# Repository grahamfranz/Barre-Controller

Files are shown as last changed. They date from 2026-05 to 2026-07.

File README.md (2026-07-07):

# Barre Controller

A parametric Eurorack-style control interface with flexible barres and top-mounted 3.5 mm jacks.

## Overview

The Barre Controller features:
- **Leaf-spring flex barres**: Flexible middle sections with piezo sensors for dynamic control
- **3.5 mm jacks**: Top-mounted panel jacks with a ~6 mm threaded barrel — any standard 3.5 mm panel-mount jack works (e.g. PJ398SM / "Thonkiconn")
- **Modular array**: Configurable number of barres with adjustable pitch

## Design Details

### Barre Architecture
Each barre consists of three sections:
- **Near end block**: Houses the near mounting screw
- **Middle (flex section)**: Thin, flexible member that bows when pressed, with piezo contact on the underside
- **Far end block**: Houses the jack pocket and far screw, with wire routing to the piezo

### Assembly
- Barres mount onto a continuous rail on the base for lateral alignment
- Two screws per barre clamp it down to the base
- Near screw: through the near end block
- Far screw: through the far end block, in front of the jack pocket

#### Hardware (per barre: 2 screws)
- **Screws:** M3, inserted from the top; the head sits proud on the end blocks (clear of the flex pad). The clamp stack is 20 mm (14 mm barre + 6 mm base), so a standard **M3×20** seats flush — the tip lands right at the base underside with full nut engagement, no protrusion and **no filing or cutting needed**. (No top counterbore: at the far screw a recessed head would break through the thin jack shoulder into the jack pocket.)
- **Nuts:** M3 hex nuts drop into the recessed **hex nut traps** on the base underside — they seat flat-to-flat and won't spin, so you can tighten entirely from the top. Because the barres see repeated pressing (cyclic load), use **nyloc nuts or a dab of threadlocker** so they don't back off. A nyloc sits slightly proud of the base underside; the rubber feet noted below absorb that.

### Printing
- **Base**: Print flat on bed (rail ridge points up)
- **Barre**: Print upside down so cutouts open upward during printing
  - Piezo indent, wire channel, jack pocket, and notch all print cleanly
  - Small bridge under jack pocket is FDM-friendly

#### Plate size and per-part STLs

The `both` render lays the base and all four barres out side-by-side, which spans
~245 mm in X — wider than most build plates. For smaller plates, print the parts
separately using the per-part STLs in `Renders/`:

| File | Part | Footprint | Notes |
|---|---|---|---|
| `barre_controller_base.stl` | Base (1×) | 130 × 157 × 9 mm | Print flat, rail up |
| `barre_controller_barre.stl` | Barre (print `num_barres`×) | 110 × 28 × 14 mm | Already in print orientation; duplicate in your slicer |
| `barre_controller_both.stl` | Base + 4 barres together | 245 × 157 mm | Single-plate layout (large plates only) |
| `barre_controller_assembled.stl` | Assembled preview | — | Visualization only, not printable as one piece |

For the default 4-barre array, print `barre_controller_base.stl` once and
`barre_controller_barre.stl` four times (arrange ~31 mm apart in Y, matching the
`both` layout). To regenerate any STL: `openscad -o Renders/barre_controller_<part>.stl -D 'part="<part>"' barre_controller.scad`

## File Structure

- `barre_controller.scad` - Main parametric model

## Customization

Key parameters in `barre_controller.scad`:

| Parameter | Default | Purpose |
|---|---|---|
| `num_barres` | 4 | Number of barres in the array |
| `barre_pitch` | 37 mm | Center-to-center spacing between barres |
| `barre_length` | 110 mm | Total length of each barre |
| `middle_thickness` | 5 mm | Flex section thickness (smaller = more flex; stiffness ~ thickness³) |
| `jack_offset_from_end` | 14 mm | Distance from far end to jack pocket center |
| `include_feet` | false | Enable corner feet for base support (experimental) |
| `foot_d` | 14 mm | Diameter of corner feet (tunable when enabled) |

## Manufacturing Notes

- Material: PLA or similar suitable for FDM printing
- Print orientation: See "Printing" section above
- **Base deflection:** The base is 6 mm thick by default, which resists press deflection reasonably well (and sets the 20 mm clamp stack for a flush M3×20). The corner feet feature is disabled by default (`include_feet = false`) because small feet don't effectively prevent base flex. If you still see flex, increase `base_thickness` in 5 mm steps to keep a standard screw flush (6 mm → M3×20, 11 mm → M3×25, 16 mm → M3×30), add adhesive rubber pads (~12 mm diameter) to the underside corners, or experiment with feet at larger `foot_d` (e.g. 18–20 mm)
- Piezo sensors are glued to the bottom of each middle section
- Jack bodies mount from below through the pocket opening; the threaded barrel passes up through the top shoulder and is secured with the jack's own nut on top
- Wire routing connects jack terminals to piezo sensor

## License

Public domain / CC0

## Enclosure Mode (Optional)

The barre controller can optionally be printed as a two-part enclosure to house a circuit board (e.g., circuit-mesh prototyping board).

### Enabling Enclosure Mode

In the OpenSCAD Customizer:
1. Set `with_enclosure` to `true`
2. Choose a render option:
   - `enclosure_shell` - Just the upper housing
   - `enclosure_panel` - Just the lower circuit board mount
   - `enclosure_both` - Both parts side-by-side for printing
   - `enclosure_assembled` - View of assembled enclosure with barres

### Enclosure Parameters

| Parameter | Default | Purpose |
|---|---|---|
| `enclosure_height` | 15 mm | Height of upper shell walls |
| `board_standoff_height` | 3 mm | Height of circuit board above lower panel |
| `piezo_hole_d` | 3.5 mm | Diameter of piezo wire pass-through holes |
| `lid_thickness` | 3 mm | Thickness of lower panel |
| `board_fastener_type` | "hex_nut" | Fastening style: "hex_nut", "square_nut", "self_tap" |
| `nut_pocket_depth` | 2.4 mm | Depth of hex-nut recess (tune per nut size) |
| `screw_margin` | 13 mm | Distance from corner to standoff center |
| `include_edge_guides` | true | Add shallow edge guides for panel alignment |
| `include_switch` | true | Add M16x2 threaded barrel power switch pocket |
| `switch_d` | 14.5 mm | Hole diameter for M16x2 switch (slight clearance) |

### Assembly

1. Print both parts (upper shell and lower panel)
2. *(Hex/square nut modes only)* Insert M3 nuts into corner pockets on the lower panel's underside
3. Mount your circuit board (e.g., circuit-mesh) to the standoffs on the lower panel using M3 screws from underneath
4. Lower the upper shell onto the lower panel, aligning corner posts
5. Insert M3 machine screws from the top and tighten into the nut pockets
6. Route piezo wires from the barres through the floor holes to your circuit board
7. Solder or connect piezo leads to your circuit board

### Power Switch (Enclosure Mode)

If `include_switch = true`, the upper shell includes a power switch pocket on the front-left face at mid-height for ergonomic thumb access.

**Switch type:** M16x2 threaded barrel (same mounting style as the Thonkiconn jacks)
- Hole diameter: 14.5 mm (for M16x2 clearance)
- Thread the switch barrel through the hole from the front
- Secure with M16x2 hex nut on the inside
- Route the switch leads down to your circuit board (e.g., between power supply and main microcontroller rail)
- Recommended switches: Latching toggle, pushbutton, or rotary switches with M16x2 threads (widely available in Eurorack supply shops)

### Backward Compatibility

When `with_enclosure = false`, the original single-piece base is rendered (default behavior). All original parameters and render modes remain unchanged.

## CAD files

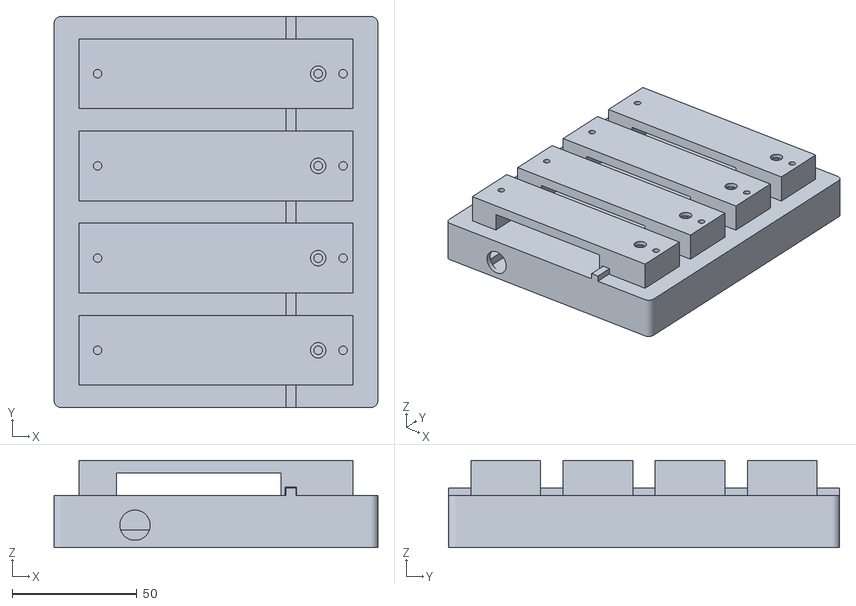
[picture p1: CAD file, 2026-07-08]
Renders/enclosure/enclosure_assembled.stl
130.0 x 157.0 x 35.0

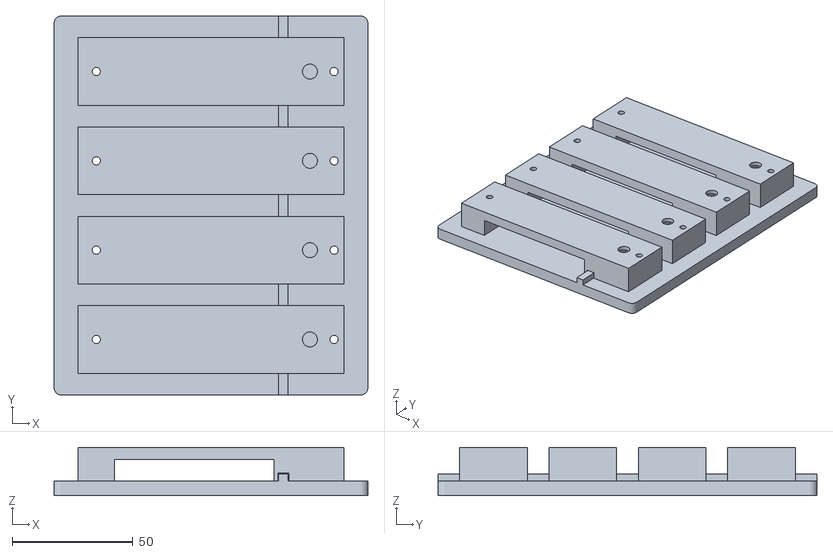
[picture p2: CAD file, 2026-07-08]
Renders/barre_controller_assembled.stl
130.0 x 157.0 x 20.0

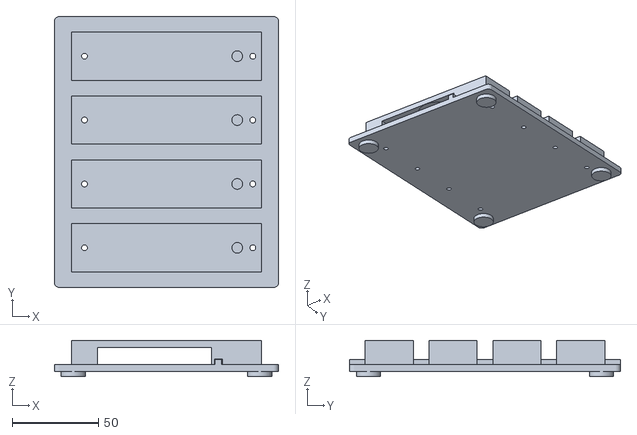
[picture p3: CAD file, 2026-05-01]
Renders/original_assembled.stl
130.0 x 157.0 x 21.0

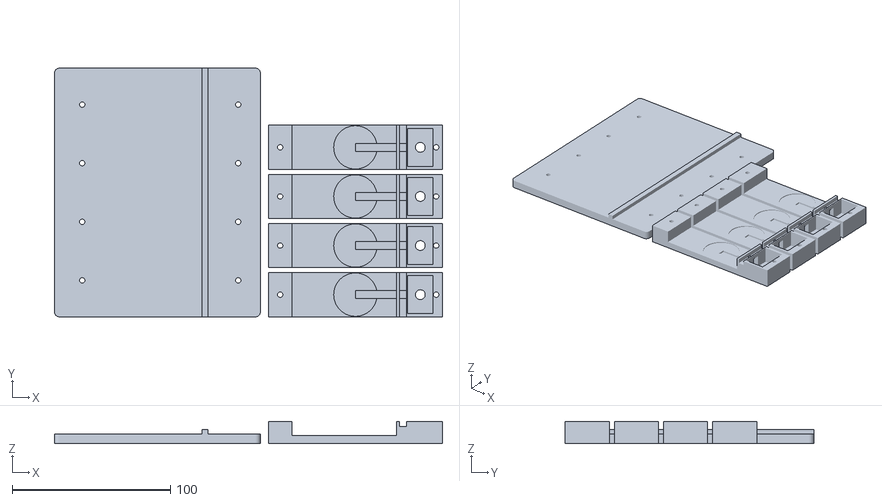
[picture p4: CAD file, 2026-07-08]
Renders/barre_controller_both.stl
245.0 x 157.0 x 14.0

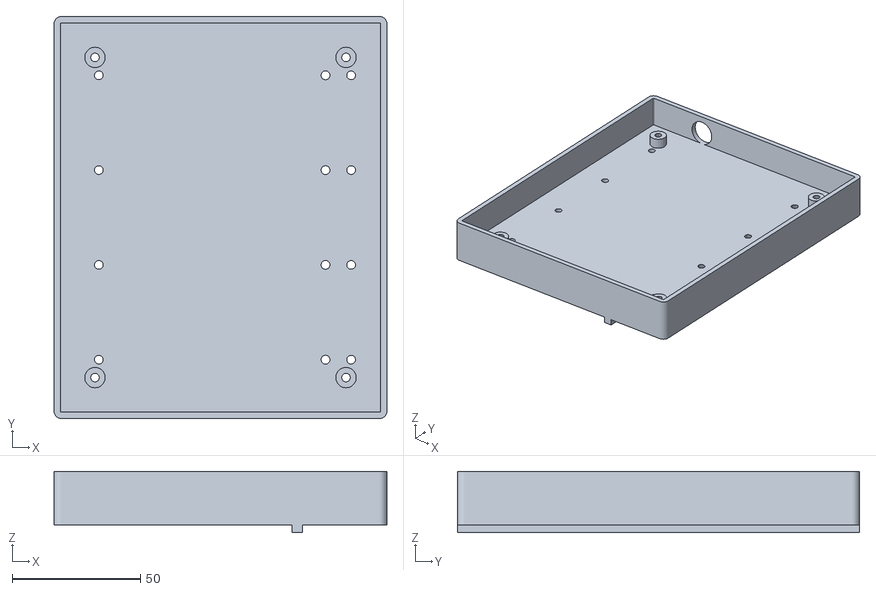
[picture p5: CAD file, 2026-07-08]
Renders/enclosure/enclosure_shell.stl
130.0 x 157.0 x 24.0

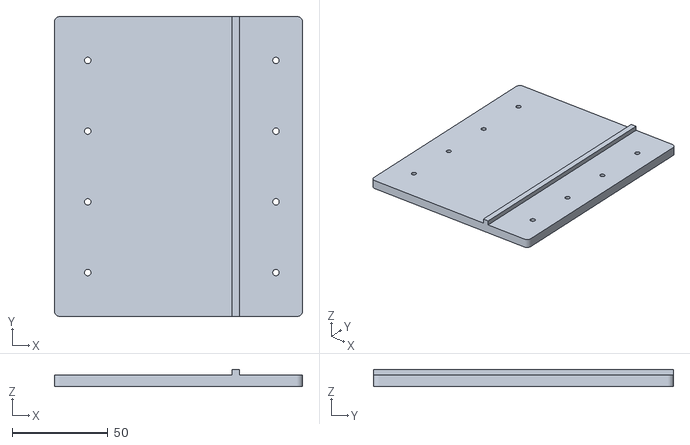
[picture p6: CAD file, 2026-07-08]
Renders/barre_controller_base.stl
130.0 x 157.0 x 9.00

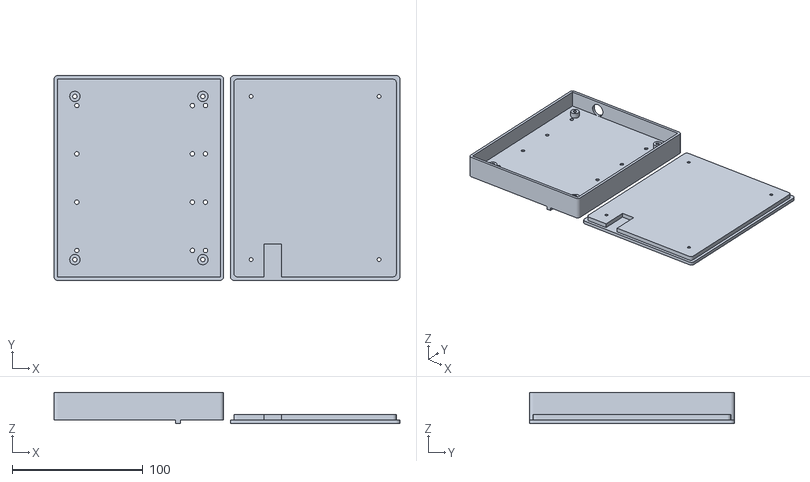
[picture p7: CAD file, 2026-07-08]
Renders/enclosure/enclosure_both.stl
265.0 x 157.0 x 24.0

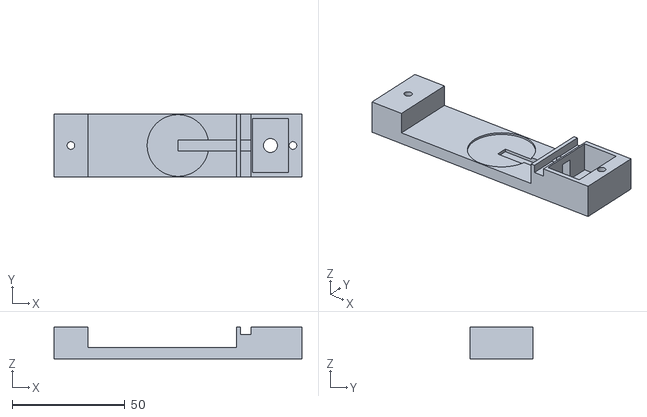
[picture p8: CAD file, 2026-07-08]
Renders/barre_controller_barre.stl
110.0 x 28.0 x 14.0

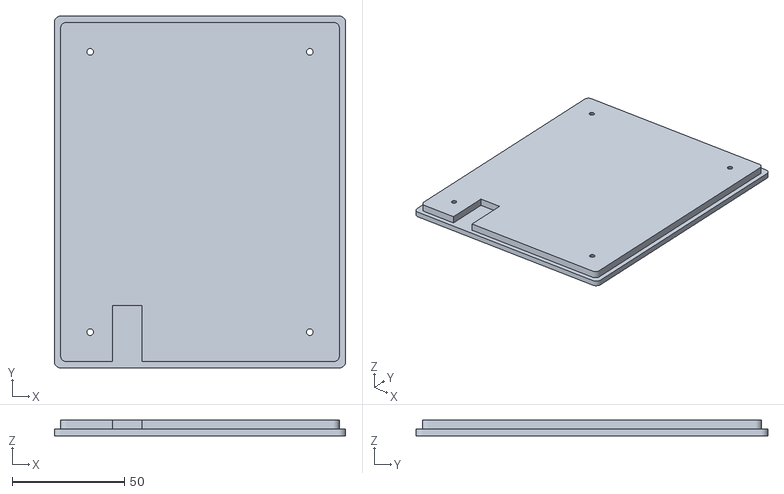
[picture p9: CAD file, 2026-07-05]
Renders/enclosure/enclosure_panel.stl
130.0 x 157.0 x 7.00

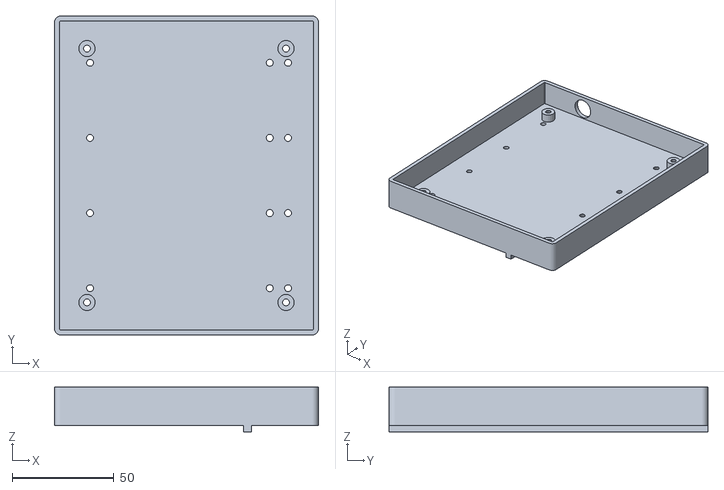
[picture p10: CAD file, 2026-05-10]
Renders/enclosure/barre_enclosure_shell.stl
130.0 x 157.0 x 22.0

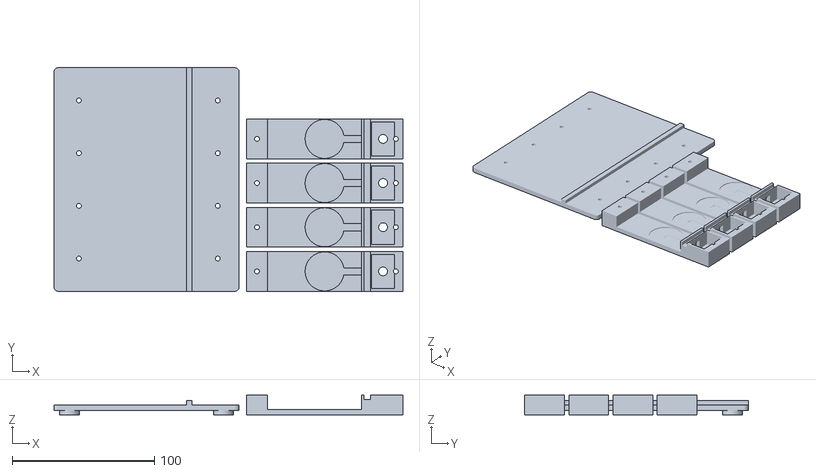
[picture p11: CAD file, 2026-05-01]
Renders/original_both_for_printing.stl
245.0 x 157.0 x 14.0

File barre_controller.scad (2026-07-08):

/* ============================================================
 *  Parametric Barre Controller v4
 *  ------------------------------------------------------------
 *  Leaf-spring flex-beam barres with top-mounted 3.5 mm jacks
 *  (sized for a standard PJ398SM / "Thonkiconn" panel jack, but
 *  any 3.5 mm panel jack with a ~6 mm threaded barrel fits) for
 *  Eurorack-style patching.
 *
 *  A single continuous rail runs across the base. Each barre
 *  has a matching notch on the underside of its far end block
 *  that drops over the rail, providing lateral alignment. Two
 *  screws per barre clamp it down.
 *
 *  Each barre has three sections along X: a near end block
 *  (near clamp screw), a thin middle flex section (piezo glued
 *  to its underside), and a far end block (jack pocket + far
 *  clamp screw + rail notch).
 *
 *  Jack orientation: the plug inserts from the top face; the
 *  jack body sits in a pocket open at the bottom face, giving
 *  access to the solder lugs and cable routing. The far screw
 *  clamps just in front of (+X of) the jack.
 *
 *  The middle's bottom sits (barre_height - middle_thickness)
 *  above the base, giving a natural flex gap so the middle can
 *  bow downward when pressed.
 *
 *  === Printing ===
 *  • Base: flat on bed. Rail is just a ridge running in Y.
 *  • Barre: print UPSIDE DOWN (flat top face on the bed). Every
 *    cutout (piezo indent, wire channel, jack pocket, notch)
 *    opens upward during printing — clean buckets and grooves.
 *
 *  License: public domain / CC0
 * ============================================================ */

/* [Render] */
part = "both"; // [barre, base, both, assembled, enclosure_shell, enclosure_panel, enclosure_both, enclosure_assembled]

/* [Array] */
num_barres  = 4;
barre_pitch = 37;   // Y centre-to-centre; must be >= barre_width

/* [Barre Geometry] */
barre_length  = 110;
barre_width   = 28;
barre_height  = 14;
middle_thickness = 5;  // pressing surface thickness; thinner = more flex (stiffness ~ thickness^3)
screw_clearance_d = 3.4;
notch_offset_from_middle = 4;

/* [Piezo] */
piezo_d = 27;
piezo_indent_clearance = 0.4;
piezo_indent_depth = 0.8;

/* [3.5 mm Jack — TS, top-mounted] */
// Sized for a PJ398SM ("Thonkiconn") panel jack, but any standard 3.5 mm
// panel jack with a ~6 mm threaded barrel fits. Plug inserts from above.
jack_plug_hole_d     = 6.2;   // for 6 mm threaded barrel
jack_plug_hole_wall  = 2.0;   // top shoulder (where the nut clamps)
jack_pocket_d        = 10;    // body pocket diameter (~9 mm body + clearance)
jack_offset_from_end = 14;
cavity_wall_y = 2;
wire_channel_w = 5;
wire_channel_d = 2;

/* [Base] */
base_margin_x  = 10;
base_margin_y  = 9;
base_thickness = 6;   // 14 mm barre + 6 mm base = 20 mm stack, so a standard M3x20 seats flush (tip at the underside) with full nut engagement; also stiffens the base against press deflection
base_corner_r  = 3;
rail_width = 4;
rail_height = 3;
screw_head_d = 6.5;      // M3 screw head diameter
screw_head_depth = 2.0;  // Depth to recess screw head flush
nut_trap_af    = 5.5;    // M3 hex nut across-flats (wrench size)
nut_trap_depth = 2.6;    // Hex nut pocket depth on base underside (M3 nut ~2.4mm + clearance)
nut_trap_d     = nut_trap_af / cos(30) + 0.2;  // across-corners + clearance for $fn=6 pocket

/* [Feet] */
include_feet = false;  // Feet don't prevent base deflection; users can add rubber pads instead
foot_d = 14;  // Diameter of feet (for experimental base support)

/* [Enclosure] */
with_enclosure = false;  // Enable two-part enclosure mode
enclosure_height = 15;   // Height of upper shell walls (mm)
rim_height = 4;          // Height of lower panel rim (mm); 4 mm is enough for lateral location
board_standoff_height = 3;  // Height of circuit board above lower panel (mm)
piezo_hole_d = 3.5;      // Diameter of piezo wire pass-through holes (mm)
lid_thickness = 3;       // Thickness of lower panel base plate (mm); >=3 needed for hex_nut fasteners
board_fastener_type = "hex_nut";  // [hex_nut, square_nut, self_tap] — hex_nut = captive nut (durable, needs lid>=3mm); self_tap allows a thinner lid
nut_pocket_depth = 2.4;  // Depth of hex-nut recess (mm)
screw_margin = 13;       // Distance from corner to screw center (mm), positions screws in corners
include_edge_guides = true;  // Add optional edge guides on lower panel

/* [Enclosure — Power Switch] */
include_switch = true;   // Add panel-mount power switch pocket
switch_d = 12.2;         // Hole diameter for 12 mm illuminated latching push button (slight clearance)

$fn = 48;
EPS = 0.02;

// ============================================================
//  Internal parameters (computed)
// ============================================================

end_length_near  = 15;
end_length_far   = 29;
notch_clearance  = 0.3;

// ============================================================
//  Derived
// ============================================================

middle_length    = barre_length - end_length_near - end_length_far;
middle_x_start   = end_length_near;
middle_x_end     = barre_length - end_length_far;
middle_bottom_z  = barre_height - middle_thickness;

notch_x_center   = middle_x_end + notch_offset_from_middle;
notch_width      = rail_width  + 2 * notch_clearance;
notch_depth      = rail_height + notch_clearance;

jack_pocket_x_center = barre_length - jack_offset_from_end;

cavity_x_span        = jack_pocket_d + 6;  // expanded for better wiring room
cavity_x_min         = jack_pocket_x_center - cavity_x_span / 2;

near_screw_x     = end_length_near / 2;
far_screw_x      = barre_length - 4;  // near the end face; kept clear of the jack cavity (see assert below)

array_span_y     = (num_barres - 1) * barre_pitch + barre_width;
base_outer_x     = 2 * base_margin_x + barre_length;
base_outer_y     = 2 * base_margin_y + array_span_y;

rail_x_center    = base_margin_x + notch_x_center;
rail_x_start     = rail_x_center - rail_width / 2;

function barre_x_start()   = base_margin_x;
function barre_y_start(i)  = base_margin_y + i * barre_pitch;
function barre_y_center(i) = barre_y_start(i) + barre_width / 2;

// Enclosure dimensions (computed when with_enclosure = true)
panel_outer_x    = base_outer_x;
panel_outer_y    = base_outer_y;
panel_margin_x   = 1;  // Small clearance between panel and shell walls
panel_width      = panel_outer_x - 2 * panel_margin_x;
panel_depth      = panel_outer_y - 2 * panel_margin_x;

// Screw boss corner positions (for both upper shell and lower panel)
boss_corner_positions = [
    [base_corner_r + screw_margin, base_corner_r + screw_margin],
    [base_outer_x - base_corner_r - screw_margin, base_corner_r + screw_margin],
    [base_corner_r + screw_margin, base_outer_y - base_corner_r - screw_margin],
    [base_outer_x - base_corner_r - screw_margin, base_outer_y - base_corner_r - screw_margin]
];

// Piezo hole positions (one per barre, positioned under the jack cavity for cable routing)
// Placed at the far end (jack) area so cables can route up to jacks or down to circuit board
piezo_hole_positions = [for (i = [0 : num_barres - 1])
    [barre_x_start() + jack_pocket_x_center, barre_y_center(i)]
];

// Power switch position: front-left area, centered in the clear wall above the base plate
switch_x = base_outer_x / 4;
switch_y = 0;
switch_z = -(enclosure_height - lid_thickness) / 2;  // Center of wall between base plate top and ceiling

echo(str("Base: ", base_outer_x, " x ", base_outer_y,
         " x ", base_thickness + rail_height, " mm"));
echo(str("Barre: ", barre_length, " x ", barre_width,
         " x ", barre_height, " mm  (middle ",
         middle_thickness, " mm, flex gap ",
         middle_bottom_z, " mm)"));
echo(str("Rail X (world): ", rail_x_center,
         ",  jack X (barre local): ", jack_pocket_x_center));

if (with_enclosure) {
    echo(str("=== ENCLOSURE MODE ==="));
    echo(str("Upper Shell: ", panel_outer_x, " x ", panel_outer_y,
             " x ", base_thickness + enclosure_height, " mm"));
    echo(str("Lower Panel: ", panel_outer_x, " x ", panel_outer_y,
             " x ", lid_thickness, " mm"));
    echo(str("Board Standoff Height: ", board_standoff_height, " mm"));
    echo(str("Piezo Holes: ", len(piezo_hole_positions), " holes, diameter ",
             piezo_hole_d, " mm"));
}

// ============================================================
//  Design-rule asserts (fail loudly on clashing parameter combos)
// ============================================================

// Far clamp screw must not cut into the jack cavity: the near edge of its
// clearance hole has to stay outboard of the cavity's far wall.
assert(far_screw_x - screw_clearance_d / 2 >= cavity_x_min + cavity_x_span,
       "far_screw_x too small: its clearance hole clips the jack cavity. Increase far_screw_x, shrink cavity_x_span, or move the jack (jack_offset_from_end).");
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

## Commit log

2026-04-28 Initial commit: barre controller with centered wire channel
    [barre_controller.scad, barre_controller.stl, barre_controller_latest.stl]
2026-04-28 Replace old render with latest STL
    [barre_controller.stl]
2026-05-01 Improve barre controller: reposition far screws, expand jack cavity, increase feet size
    [barre_controller.scad, barre_controller.stl]
2026-05-01 feat: add enclosure parametric controls
    [barre_controller.scad]
2026-05-01 feat: add derived values for enclosure geometry
    [barre_controller.scad]
2026-05-01 feat: add upper_shell module with walls and piezo holes
    Adds upper_shell() module for enclosure mode, providing a rounded-rect
    solid body extended by enclosure_height, continuous barre mounting rail,
    vertical screw through-holes for barre clamping, M3 corner boss clearance
    holes, and piezo wire pass-through holes at floor level.
    [barre_controller.scad]
2026-05-01 feat: add lower_panel module with standoffs and nut pockets
    Adds lower_panel() module for enclosure mode — a flat panel with
    rounded corners, four M3 standoffs at boss_corner_positions, M3
    clearance holes through standoffs and panel, hex-nut/square-nut
    pockets recessed into the underside, and optional edge guide lips.
    [barre_controller.scad]
2026-05-01 fix: correct square-nut pocket centering and remove dead variable
    [barre_controller.scad]
2026-05-01 feat: add corner posts to upper_shell for fastening
    [barre_controller.scad]
2026-05-01 feat: add enclosure render modes and update render section
    - Extend `part` parameter enum with four new enclosure options:
    enclosure_shell, enclosure_panel, enclosure_both, enclosure_assembled
    - Replace flat render dispatch with with_enclosure-gated conditional
    that routes enclosure parts to upper_shell/lower_panel modules while
    preserving all original modes for backward compatibility
    [barre_controller.scad]
2026-05-01 feat: add echo statements for enclosure dimensions
    [barre_controller.scad]
2026-05-01 docs: add enclosure mode documentation to README
2026-05-01 render: add enclosure and original design renders for visualization
    [enclosure_assembled.stl, enclosure_both_for_printing.stl, lower_panel.stl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]
2026-05-01 fix: make upper_shell hollow with open bottom and visible piezo holes
    [enclosure_assembled_fixed.stl, upper_shell_fixed.stl]
2026-05-01 fix: rewrite upper_shell with explicit hollow walls and visible rail
    [barre_controller.scad]
2026-05-01 render: update upper_shell and enclosure_assembled with corrected hollow design
    [enclosure_assembled.stl, upper_shell.stl]
2026-05-01 fix: correct upper shell wall positioning and lower panel geometry for proper enclosure assembly
    - Fixed upper_shell walls to start at Z=base_thickness, creating a true hollow enclosure rather than solid mass
    - Walls now extend cleanly upward from the floor instead of being embedded in it
    - Corrected lower_panel to use full base dimensions for proper alignment with upper shell
    - Ensured corner posts and standoffs align correctly for hex-nut screw fastening
    - Piezo holes properly positioned at the upper shell floor for wire routing to circuit board below
    - All enclosure render modes (shell, panel, assembled) now work correctly with proper geometry
    [barre_controller.scad]
2026-05-01 feat: add corrected render files for all design modes
    Renders include:
    - Original design (backward compatible): barre, base, both_for_printing, assembled
    - Enclosure design: upper_shell, lower_panel, enclosure_both_for_printing, enclosure_assembled
    All renders use the corrected geometry with proper wall positioning and panel alignment.
    [assembled.stl, barre.stl, barre_controller.stl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]
2026-05-01 fix: switch to friction-fit enclosure design without screw fastening
    - Removed screw boss posts from upper shell corners
    - Removed hex-nut pockets and screw fastening from lower panel
    - Added bottom lip in upper shell for panel friction fit
    - Lower panel now slides into enclosure opening with 0.3mm clearance
    - Kept M3 holes in panel for circuit board fastening
    - Simplified corner geometry to eliminate weird ridge artifacts
    - Assembly: barres on top, electronics in enclosure below, panel friction fits at bottom
    [assembled.stl, barre_controller.scad, enclosure_assembled.stl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]
2026-05-01 fix: correct enclosure geometry - tray with walls extending down
    - Upper shell is now a tray where barres mount ON TOP
    - Walls extend DOWN from the mounting surface to create enclosure
    - Top mounting surface at Z=0, walls extend to Z=-enclosure_height
    - Lower panel sized to fit inside walls, positioned at bottom opening
    - Piezo holes on top surface for wire routing down to electronics
    - Clean friction fit assembly: barres on top, lower panel slides in bottom
    [assembled.stl, barre.stl, barre_controller.scad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]
2026-05-01 fix: increase wire hole diameter and reposition under jack cavity
    - Increased piezo_hole_d from 1.5mm to 3.5mm for easier cable routing
    - Repositioned holes from barre center to jack pocket area for better cable path
    - Allows cables to route both up to jacks and down to circuit board below
    [barre_controller.scad, enclosure_assembled.stl, lower_panel.stl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]
2026-05-01 feat: add corner standoff tubes and screw holes for enclosure assembly
    - Added hollow tube standoffs extending down from upper shell corners
    - Standoff tubes (8mm OD, 3.4mm ID) support circuit board inside enclosure
    - M3 screw holes through top surface corners to connect shells together
    - Lower panel has clearance holes for standoff tubes to pass through
    - M3 holes in lower panel for circuit board fastening
    - Assembly: screws pass through hollow tubes, connecting upper shell to lower panel
    - Circuit board sits on top of hollow tubes at the proper height
    [barre_controller.scad, enclosure_assembled.stl, enclosure_both_for_printing.stl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]
2026-05-01 fix: position corner screw holes correctly on top surface
    - Fixed screw hole positioning to cut through the top surface (not above it)
    - Holes are now clearly visible in the top for connecting upper shell to lower panel
    - Hollow standoff tubes with M3 clearance for screw pass-through
    [barre_controller.scad, enclosure_assembled.stl, enclosure_both_for_printing.stl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]
2026-05-01 fix: correct standoff tube extrusion direction
    - Fixed tube cylinders to extend downward (was using negative height)
    - Tubes now properly visible extending from top surface down into enclosure
    - Tubes provide structural support for circuit board and screw pass-through
    [barre_controller.scad, enclosure_assembled.stl, lower_panel.stl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]
2026-05-01 fix: add hex screw recesses and move corner screws away from barres
    - Increased screw_margin from 5 to 45mm to move corner screws away from barre mounting area
    - Added hexagonal recesses (6.5mm hex, 2.5mm deep) for M3 hex cap screw heads to sit flush
    - All corner screws now have 5mm+ clearance from nearest barre
    - Hollow offset tubes ready for circuit board support
    [barre_controller.scad, enclosure_assembled.stl, enclosure_both_for_printing.stl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]
2026-05-01 fix: hollow tubes all the way through and move screws back to corners
    - Fixed hollow interior of standoff tubes to extend fully (no gaps at ends)
    - Reduced screw_margin from 45 to 35 to keep corner screws in corners
    - Corner screws now positioned 1-2mm clear of barre edges with proper spacing
    - Hex recesses for M3 cap screw heads on top surface
    [barre_controller.scad, enclosure_assembled.stl, enclosure_both_for_printing.stl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]
2026-05-01 simplify: move corner screws to corners and remove hex recess
    - Reduced screw_margin from 35 to 8, positions corner screws in actual corners
    - Removed hex recess, corner screw holes now normal M3 clearance holes
    - Lower panel friction fits into upper shell with 0.3mm clearance on all sides
    - Cleaner, simpler design for assembly
    [barre_controller.scad, enclosure_assembled.stl, enclosure_both_for_printing.stl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]
2026-05-01 feat: add rim to lower panel, half-height standoffs, tight screw holes, and hex-nut pockets
    [barre_controller.scad]
2026-05-01 render: add enclosure STL exports (panel, shell, both, assembled)
    [enclosure_assembled.stl, enclosure_both.stl, enclosure_panel.stl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]
2026-05-01 chore: organize enclosure renders into folder, remove superpowers docs
    [enclosure_assembled.stl, enclosure_both.stl, enclosure_panel.stl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]
2026-05-01 chore: remove old enclosure renders
    [enclosure_both_for_printing.stl, lower_panel.stl, upper_shell.stl]
2026-05-04 Fix enclosure design: rounded corners, screw boss clearance, internal space
    - Extend rounded corners down full height of shell walls for consistent appearance
    - Increase lower panel standoff height from 1.5mm to 3mm for PCB component clearance
    - Reduce upper shell standoff height to 5mm to leave room for PCB and components
    - Clean up old render files, rename to barre_enclosure_* convention
    [barre_controller.scad, barre_enclosure_assembled.stl, barre_enclosure_shell.stl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]
2026-05-04 Remove feet by default, add M16x2 power switch mount to enclosure
    - Disable feet feature by default (include_feet=false) since small feet don't prevent base deflection
    - Feet remain tunable via include_feet and foot_d parameters for experimentation
    - Add 14.5mm circular switch hole through front wall of enclosure upper shell at ergonomic mid-height
    - Switch mounts M16x2 threaded barrel (same style as Thonkiconn jacks) with hex nut on back
    - Update README with manufacturing notes, switch parameters, and assembly instructions
    - Render updated STL files with new defaults
    [barre_controller.scad, both_for_printing.stl, enclosure_both_for_printing.stl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]
2026-05-10 Flip enclosure shell to print top-face-down; regenerate all renders
    Add upper_shell_for_print() that rotates the shell 180° so the flat
    mounting surface is on the bed — standoffs print as pillars, holes open
    cleanly, and no ceiling bridging is needed. Update enclosure_shell and
    enclosure_both render modes to use this orientation; fix enclosure_both
    panel Z offset to match. Regenerated all STLs from current defaults.
    [assembled.stl, barre.stl, barre_controller.scad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]
2026-05-10 Fix switch hole size and position
    Switch to 12.2 mm hole for a standard 12 mm illuminated latching push
    button (previous 14.5 mm left <0.25 mm wall material top and bottom).
    Center the hole in the wall height (switch_z = -enclosure_height/2)
    so it no longer breaches the top plate. Regenerated enclosure STLs.
    [barre_controller.scad, barre_enclosure_assembled.stl, barre_enclosure_shell.stl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]
2026-05-10 Thin base plate to 1.5mm, fix switch hole position
    lid_thickness 3mm → 1.5mm: the friction fit comes from the rim, not
    the base plate, so 1.5mm is plenty. Changed default fastener to
    self_tap (hex_nut pockets need >=3mm lid — noted in comment).
    With lid=3mm the available wall above the plate was 12mm, narrower
    than the 12.2mm switch hole — no valid switch_z existed. At 1.5mm the
    available wall is 13.5mm, giving 0.65mm clearance top and bottom.
    switch_z now computed as -(enclosure_height - lid_thickness) / 2 so
    it stays centered regardless of parameter changes. Regenerated enclosure STLs.
    [barre_controller.scad, barre_enclosure_assembled.stl, barre_enclosure_shell.stl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]
2026-05-10 Cut switch body clearance through locating rim
    The rim front face sits only 0.3 mm behind the shell wall, directly
    blocking the switch body from seating. Subtracts a cylinder (switch_d
    + 1 mm) through the full rim depth at the switch position so the body
    has clearance into the interior. Regenerated enclosure STLs.
    [barre_controller.scad, barre_enclosure_assembled.stl, barre_enclosure_shell.stl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]
2026-05-10 Fix enclosure panel: shorten rim and localize switch clearance
    Reduce rim_height 7 → 4 mm; 4 mm is sufficient for lateral location and
    friction fit. Replace the full-length cylinder tunnel (151 mm end-to-end
    through the plug) with a 25 mm rectangular notch at the front of the rim
    in the switch band — the switch body passes over the absent section rather
    than through a tunnel, and the rest of the rim stays solid.
    [barre_controller.scad, enclosure_panel.stl]
2026-05-10 Re-render enclosure_both and enclosure_assembled after panel changes
    Reflects reduced rim_height (7 → 4 mm) and localized switch body notch
    replacing the full-length cylinder tunnel in the lower panel.
    [barre_enclosure_assembled.stl, enclosure_both_for_printing.stl]
2026-05-14 Add screw head countersinks to all screw holes
    Recess screw heads on bottom-facing surfaces (base, barre, shell, panel)
    so they don't protrude. M3 countersinks 5.5mm dia × 1.5mm deep; barre/base
    screw countersinks 6.5mm dia × 2.0mm deep for larger mounting screws.
    [barre_controller.scad, barre_controller_assembled.stl, barre_controller_both.stl]
2026-05-14 Re-render enclosure mode with countersink fixes
    Render all four enclosure presets (shell, panel, both, assembled) with
    screw head countersinks applied. Remove old/unused renders from both root
    and enclosure directory to keep artifacts clean.
    [assembled.stl, barre.stl, barre_enclosure_assembled.stl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]
2026-06-27 Add per-part STLs, hex nut traps, and thicker flex pad
    - Render standalone base and barre STLs so the parts fit smaller
    build plates individually (the combined "both" layout is ~245mm
    wide). Document the per-part print workflow in the README.
    - Replace the base's round screw-head counterbore with a hex nut
    trap on the underside so M3 nuts seat flat-to-flat and can't
    spin; tightening is now top-side only. Add nut_trap_* params.
    - Thicken the flex pad (middle_thickness 4 -> 5mm) for rigidity;
    ~2x stiffer at low infill. Re-render affected/assembled STLs.
    - Add an assembly hardware spec (M3 from top, ~21mm thread,
    nyloc/threadlocker) to the README.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
    [barre_controller.scad, barre_controller_assembled.stl, barre_controller_barre.stl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]
2026-07-05 Prep for public release: generalize jack spec, fix docs, standard screw, add LICENSE
    - Generalize jack to any standard 3.5 mm panel jack (~6 mm barrel), not Thonk-only
    - Remove wrong/pointless ASCII header diagram; fix side-mounted -> top-mounted
    - Fix false "near end block houses the piezo" claim (piezo is under the middle flex)
    - Remove the barre screw-head counterbore (incl. the vestigial underside one);
    head sits proud on top and a standard M3x20 reaches full nut engagement via the
    base underside nut traps -> no filing. A top counterbore is avoided because the
    far screw's head would breach the thin jack shoulder into the jack cavity.
    - Re-render barre/base/both/assembled STLs for t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
    [barre_controller.scad, barre_controller_assembled.stl, barre_controller_barre.stl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]
2026-07-05 Enclosure: default to captive hex-nut fasteners with a 3 mm lid
    Switch board_fastener_type default self_tap -> hex_nut and lid_thickness
    1.5 -> 3 mm so the nut pocket has material to sit in. Captive nuts survive
    repeated open/close cycles where self-tapping into PLA would strip, and
    match the base's barre-screw nut traps. Brings the code in line with the
    README, which already documented these as the defaults.
    Re-render enclosure panel/both/assembled STLs (shell is unaffected).
    [barre_controller.scad, enclosure_assembled.stl, enclosure_both.stl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]
2026-07-07 Thicken base to 6 mm so a standard M3x20 seats flush
    With the 4 mm base the clamp stack was 18 mm, so an M3x20 (the screw we
    spec) protruded ~2 mm past the base underside and stopped it sitting flat.
    Bumping base_thickness 4 -> 6 makes the stack 20 mm: the M3x20 tip lands
    exactly at the underside with full nut engagement. Also stiffens the base
    against the press deflection noted in the README.
    top_thickness in the enclosure shell tracks base_thickness, so the shell
    top thickens to 6 mm too. Re-render base/both/assembled and enclosure
    shell/both/assembled (barre and enclosure_panel are unaffected).
    [barre_controller.scad, barre_controller_assembled.stl, barre_controller_base.stl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]
2026-07-08 Move far screw clear of the jack cavity; add design-rule asserts
    far_screw_x barre_length-5 -> -4 so the clearance hole no longer clips
    the jack pocket (0.7 mm overlap -> 0.3 mm clearance), giving the jack an
    uninterrupted pocket wall. Add assert guards that fail loudly on clashing
    parameter combos: far-screw/cavity clearance, barre_pitch >= barre_width,
    and hex_nut lid depth (lid_thickness >= nut_pocket_depth + floor).
    Re-render the 7 parts that use far_screw_x (barre/base/both/assembled and
    enclosure shell/both/assembled); enclosure_panel is unaffected.
    [barre_controller.scad, barre_controller_assembled.stl, barre_controller_barre.stl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]
